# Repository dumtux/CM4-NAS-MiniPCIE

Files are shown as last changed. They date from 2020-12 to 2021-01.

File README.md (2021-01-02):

**Rapberry PI compute module 4 NAS PCB for using JLCPCB.com. (pre-test version)**

# General view of PCB based on processing gbr files on JLCPCB.com

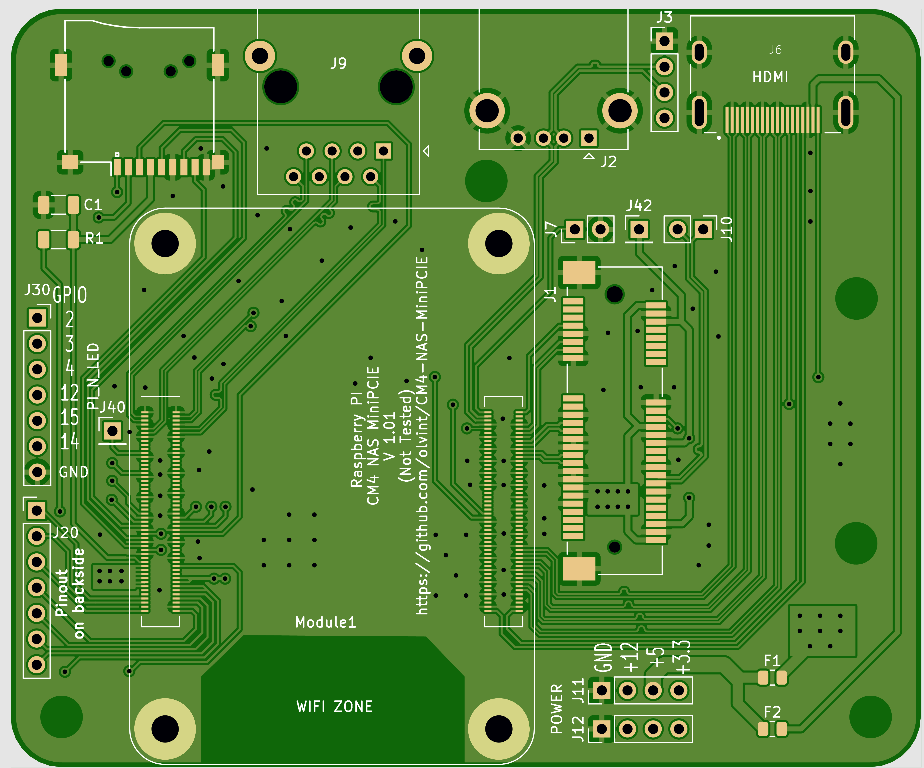
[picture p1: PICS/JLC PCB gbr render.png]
PCB_view


Main purpose of design is to make NAS with more reliable SATA connection comparing to USB-to-SATA converters. SATA controllers can be connected through MiniPCIe slot. There are variety of cards in market, mainly my intend was to use this for 2 SATA (see picture below). This is half size card. Cards for 4 SATA with RAID controller also can be connected. 

**Design is made using nighly version of KiCAD 5.99.0**
**Please study Raspberry PI CM4 datasheet**

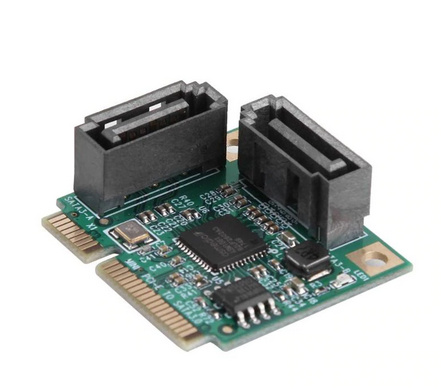
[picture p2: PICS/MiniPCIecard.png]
card


# Differential lines
*PCB was designed by a newcomer. All steps made are listed below. This section is very important and risky. Mistakes can be made.  90 R and 100R impedance differential lines are used.Calculations of differential lines are made using JLCPCB internal [calculator](https://cart.jlcpcb.com/impedanceCalculation)*

Results of calculation - [90R](https://raw.githubusercontent.com/olvint/CM4-NAS-MiniPCIE/main/PICS/JLCPCB%20Impedance%2090R.png) and [100R](https://raw.githubusercontent.com/olvint/CM4-NAS-MiniPCIE/main/PICS/JLCPCB%20Impedance%20100R.png)

Those results put in KiCAD.
KiCAD_Layers

JLC7628 [Stackup](https://cart.jlcpcb.com/impedance) used all settings transfered to [KiCAD stackup](https://raw.githubusercontent.com/olvint/CM4-NAS-MiniPCIE/main/PICS/KiCAD%20Stack.png)

All vias minimal diameter is 0.45 as price will be much higher for VIAs of less size.

# PCB description
## Sockets on PCB
- MiniPCIe slot (designed for hlaf-size cards)
- HDMI in order to use device as media player
- Gigabit LAN
- SD card slot for using CM4’s without eMMC
- USB A 2.0 socket for connecting periphery like Zigbee.
- MicroUSB for installing firmware to CM4 and power supply.
All sockets placed on top edge of PCB for more reliable use and easy design of 3D print case.

## Footprints
All sockets footprints selected to be most common. In standard library of  KiCAD I did not found suitable MicroSD socket. And ofcource footprint of CM4 is also taken from Raspberry PI CM4 IO borad. All external footprints are in folder LIBS.
I wanted to install all sockets on one side of the board and there was not much space. MicroUSB socket I put on other side of the board below MicroSD socket.

## On board connectors.
### Power input. 
There are 2 connectors with 4 pins (GND, +12V, +5V, +3.3V) Connectors can be used for powering board and soldering cable for powering HDDs. 
- +12 V is only used for HDD. Board has 2 interconnected pins, but level +12 V not used on board. MiniPCIe does not have +12V input.
- +5V used for powering CM4 module and giving power to USB and HDMI. Two SMD resettable fuses installed to protect board from short circuit. 
- +3.3 V used for powering PCI-to-SATA module. Nothing else.
- 1.5 V. Special connector made above PCIe slot.  Generaly this level is not required. It is planned to use SATA module based on chip ASM1061 that has [Integrated 3.3V to 1.2V switch regulator](https://www.asmedia.com.tw/eng/e_show_products.php?cate_index=166&item=118). 

Initial CM4 IO Borad has more copmplicated power system with different ICs for protecting not only from short circuit but, under voltage, overload etc.

### GPIO.
Left side of board has GPIO connector and small connector for selecting level of GPIO (GPIO_Vref)
- GPIO 2
- GPIO 3
- GPIO 4
- GPIO 12
- GPIO 15
- GPIO 14

### Service conections and LEDs
There is a connector with following signals
- nRPIBOOT
- PI_POWER_LED
- Global_EN
- nEXTRST
- Analog_P1
- Analog_P0
- RUN_PG
- PI_N_LED

### Other connectors
- USG_OTG connector used to connect USB_OTG_ID pin of CM4 for installing firmware to eMMC. 
- USB hub connecor Connector with 4 pins GND, D+, D-, +5V can be used to connect external USB hub if you need it in your project.
- MiniPCIe USB D+/D-. MiniPCIe slot also has connections for D+ and D- another connector used for it. This is not connected to CM4 D+/D- lines.
- One GND connector just for the case.

### GBR files
GBR files are prepared in [FAB](https://github.com/olvint/CM4-NAS-MiniPCIE/tree/main/FAB) folder. Also archive prepared FAB_JLCPCB.zip for making order. *Please note that you need to turn on option **Impedance** and select JLCPCB7628 stackup*

### KiCAD view
Front
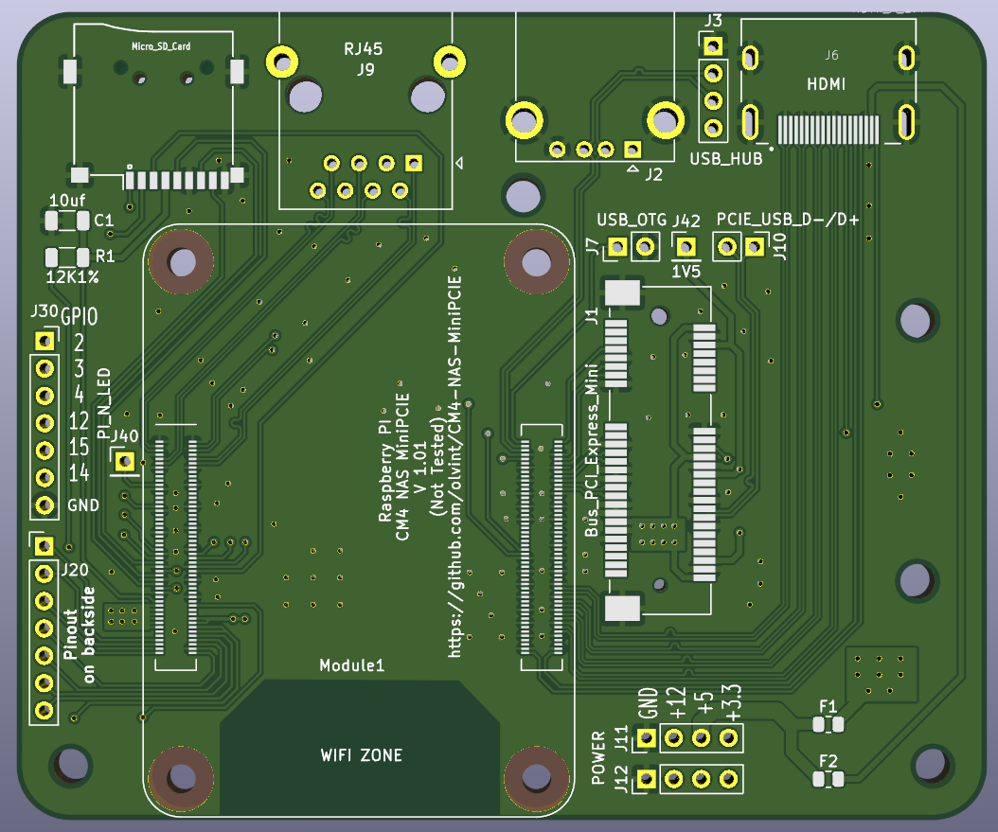
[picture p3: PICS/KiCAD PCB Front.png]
Front


Back
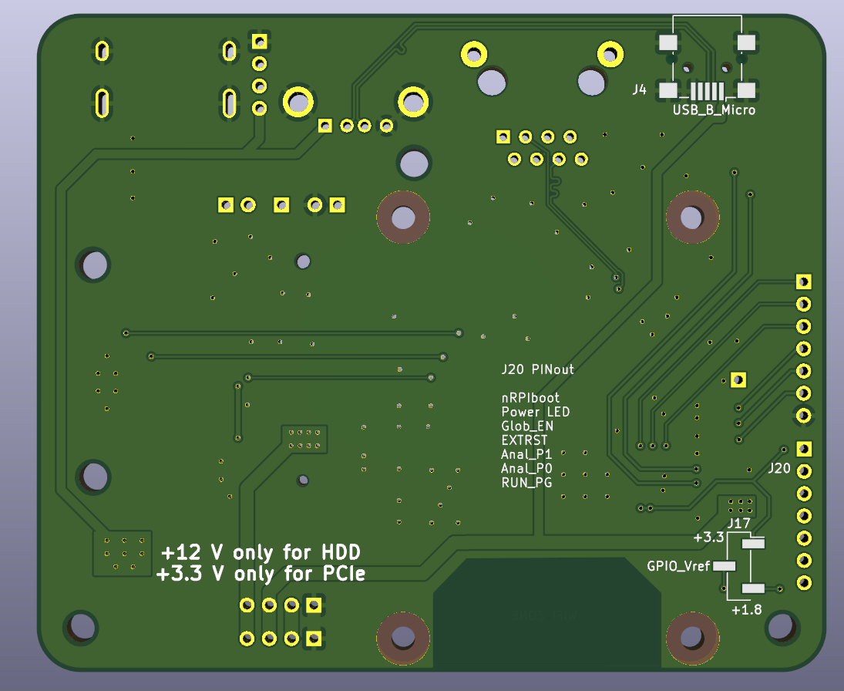
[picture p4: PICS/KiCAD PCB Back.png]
Back


Update 28.12.2020 - Rerouted some tracks. Moved MicroUSB below MicroSD.
Update 02.01.2021 - Rerouted a lot of tracks. Added beauty.

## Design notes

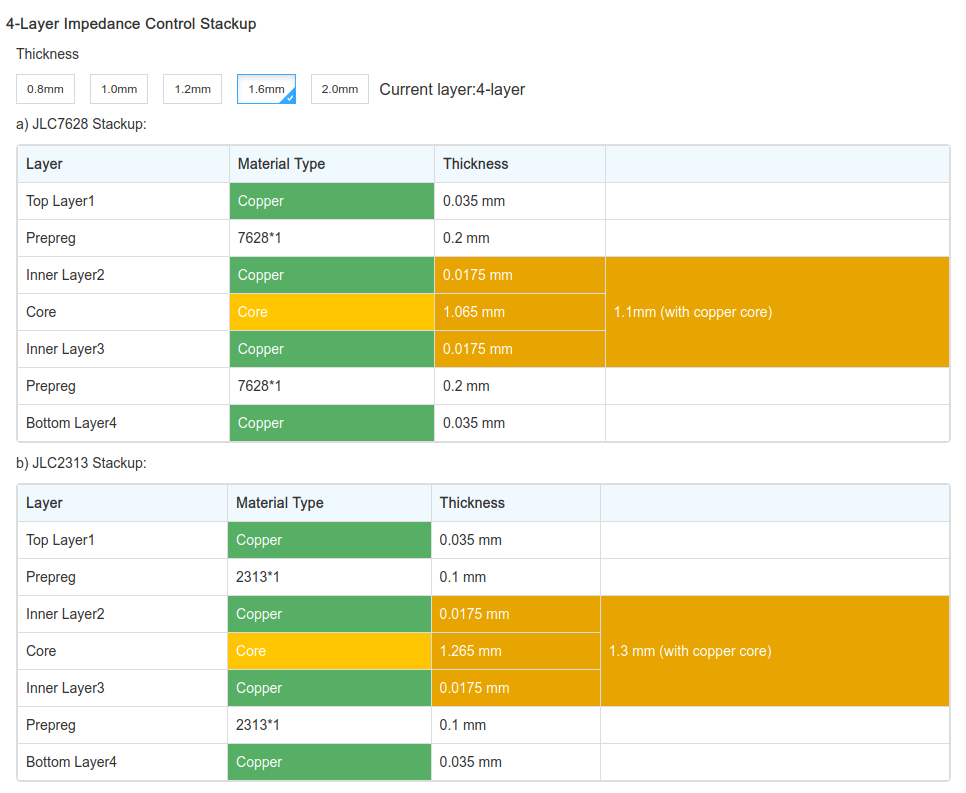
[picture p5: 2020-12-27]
PICS/JLCPCB Stack.png

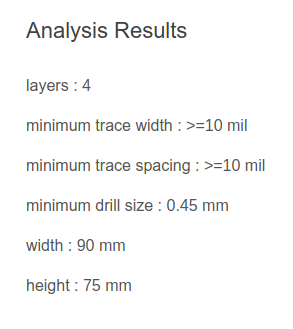
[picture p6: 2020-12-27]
PICS/JLCPCB Analysis.png

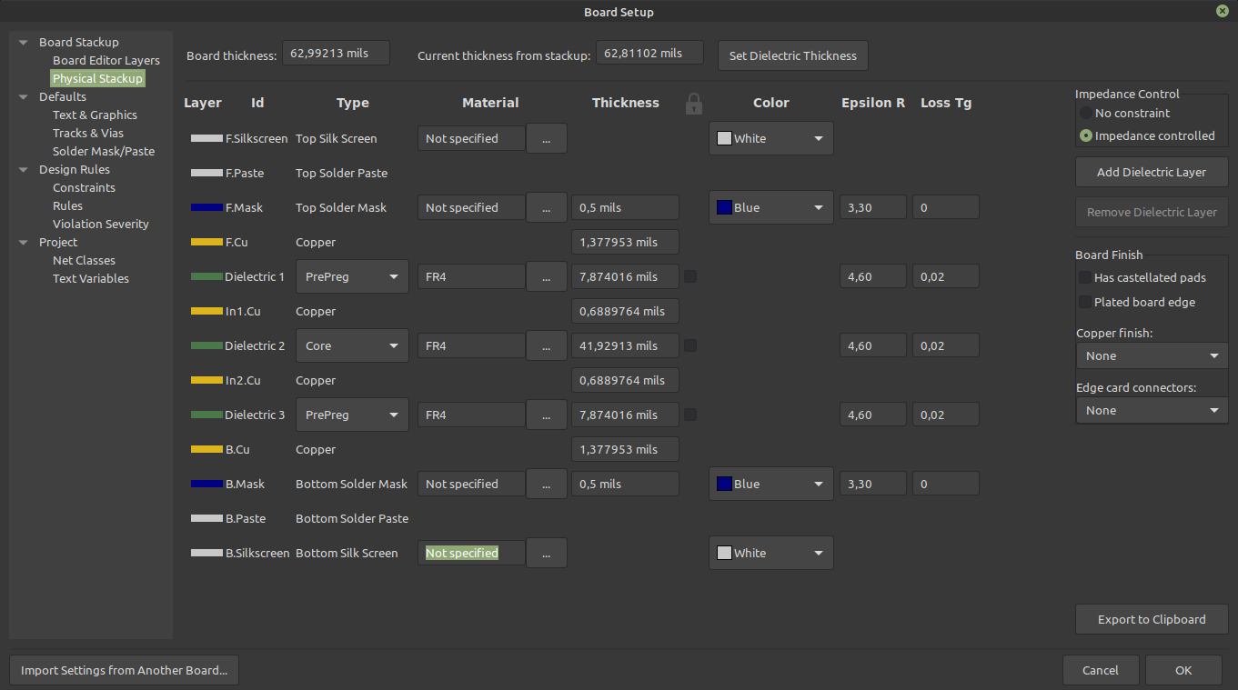
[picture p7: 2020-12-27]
PICS/KiCAD Stack.png

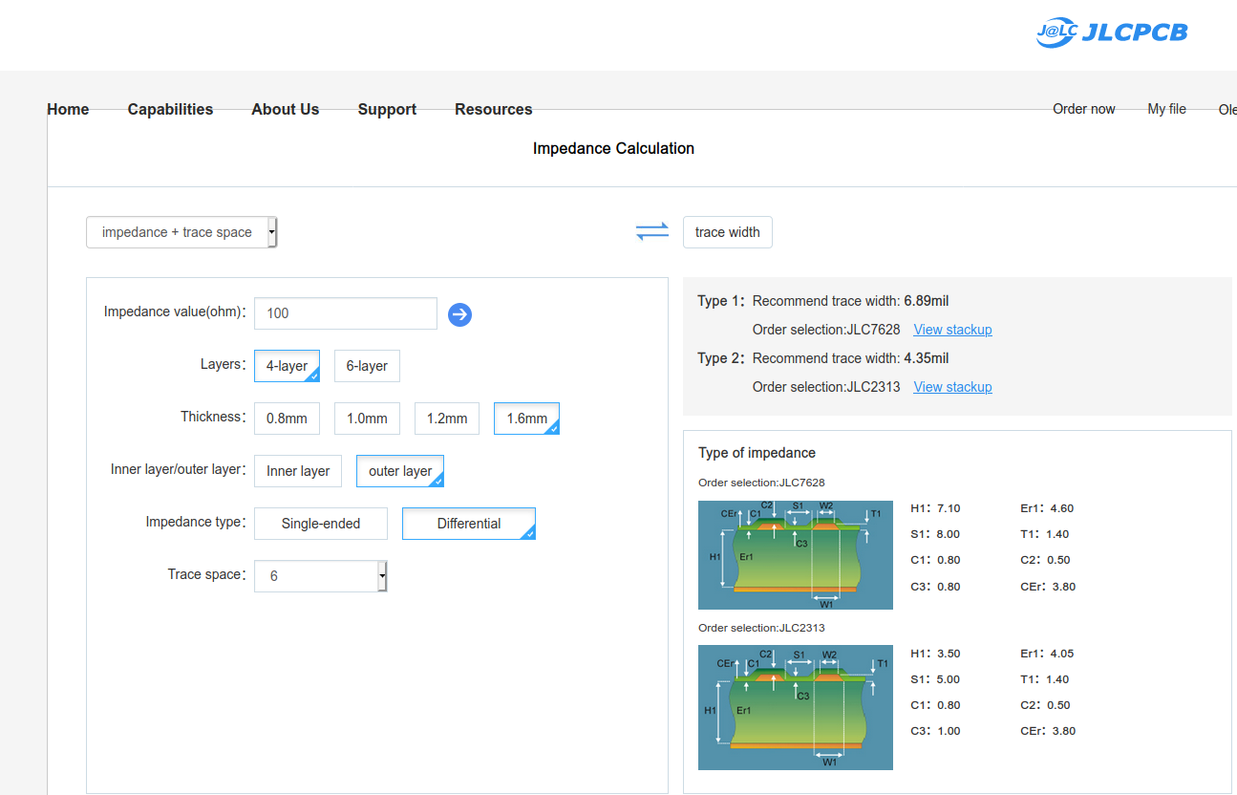
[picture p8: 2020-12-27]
PICS/JLCPCB Impedance 100R.png

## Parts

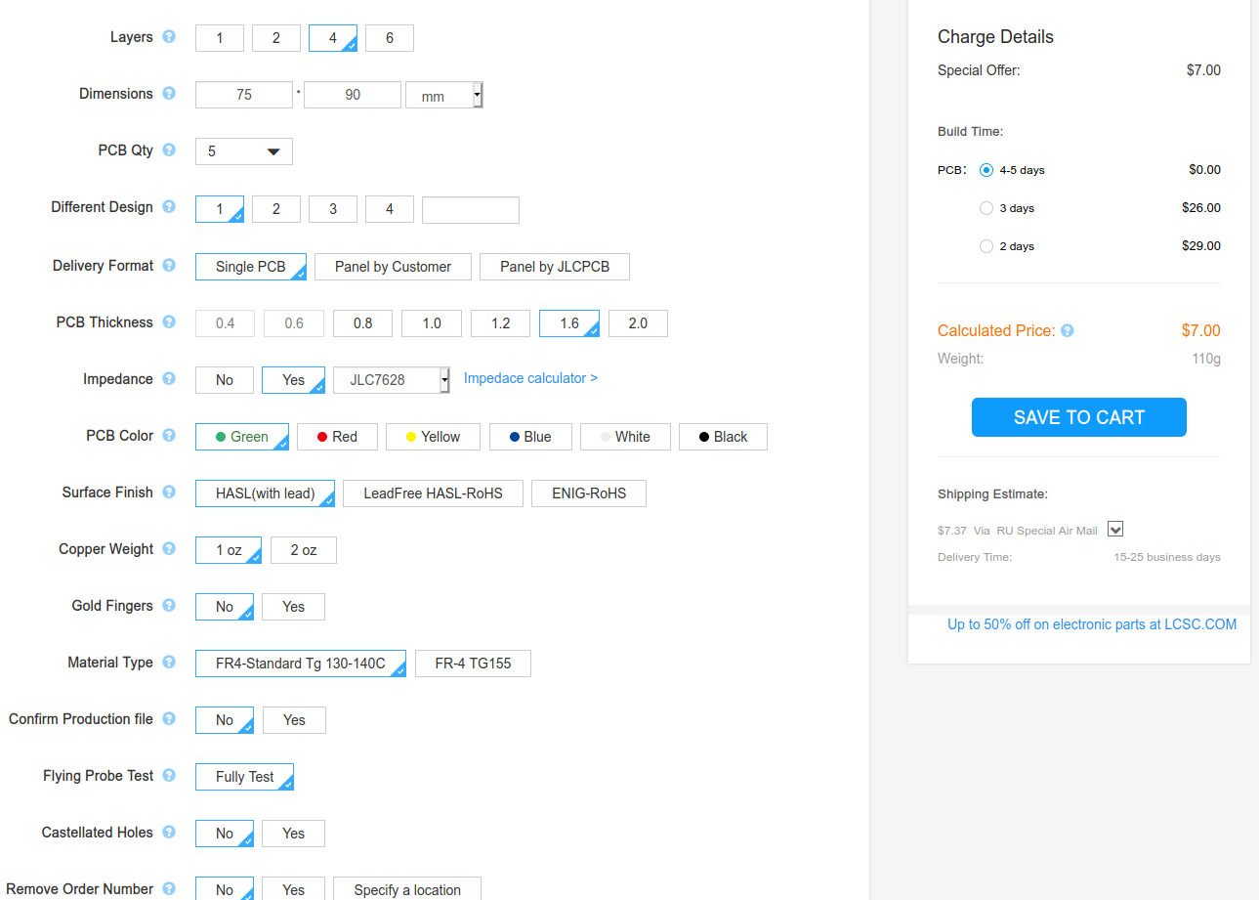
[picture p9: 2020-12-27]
PICS/JLC PCB Order.png

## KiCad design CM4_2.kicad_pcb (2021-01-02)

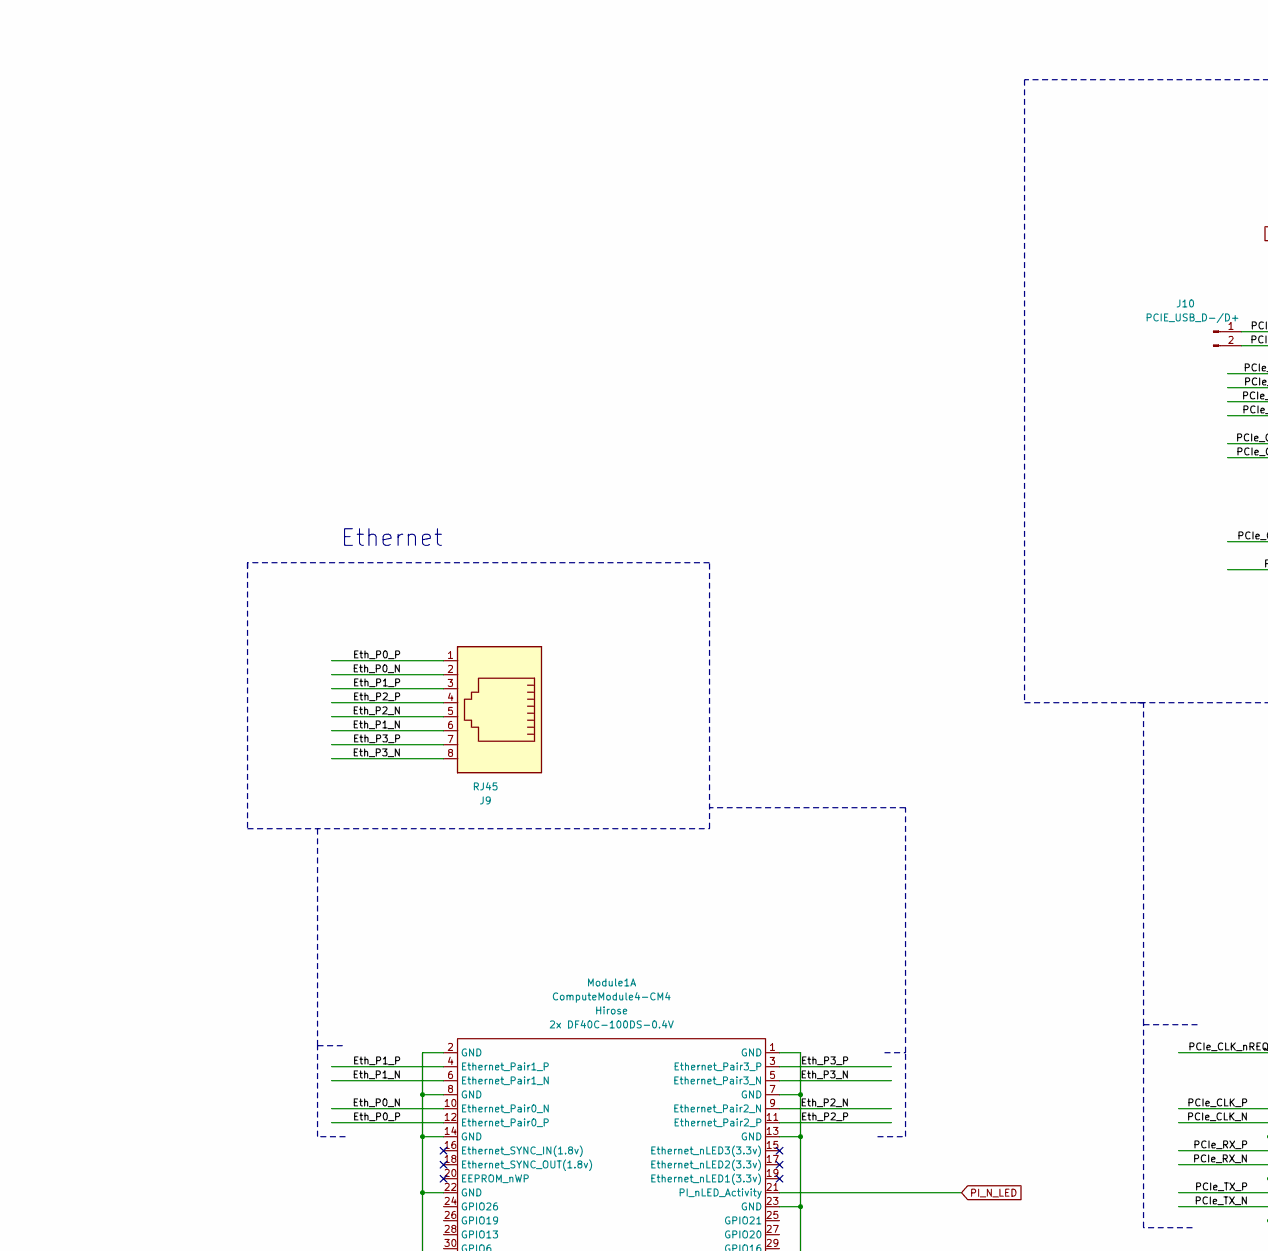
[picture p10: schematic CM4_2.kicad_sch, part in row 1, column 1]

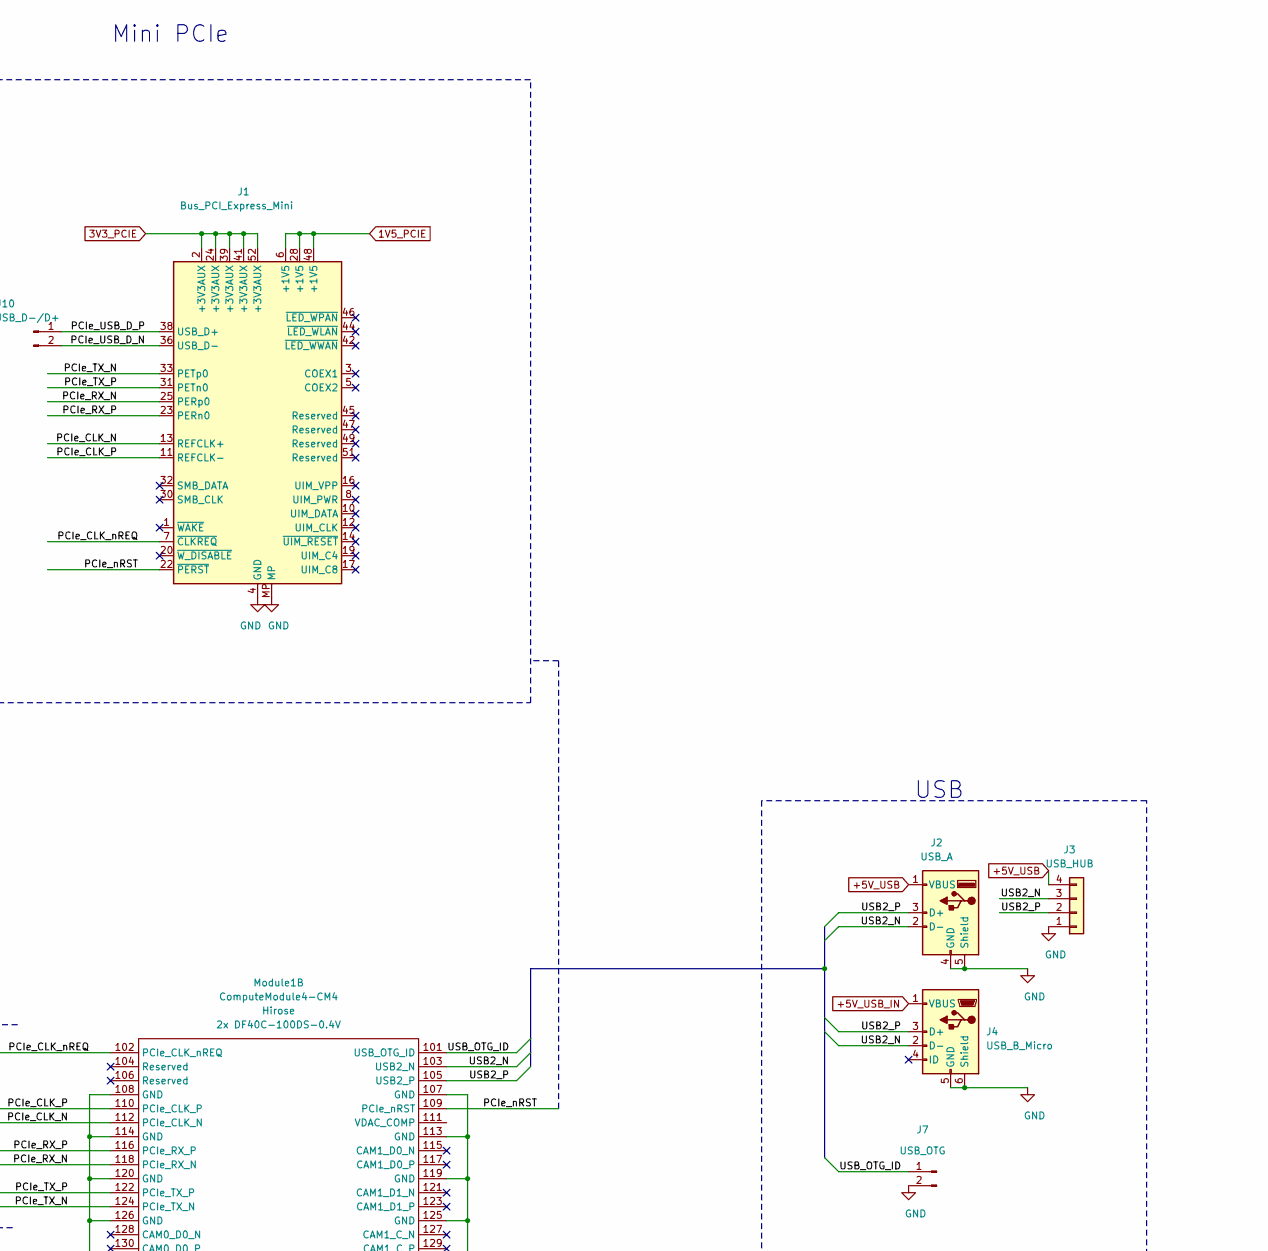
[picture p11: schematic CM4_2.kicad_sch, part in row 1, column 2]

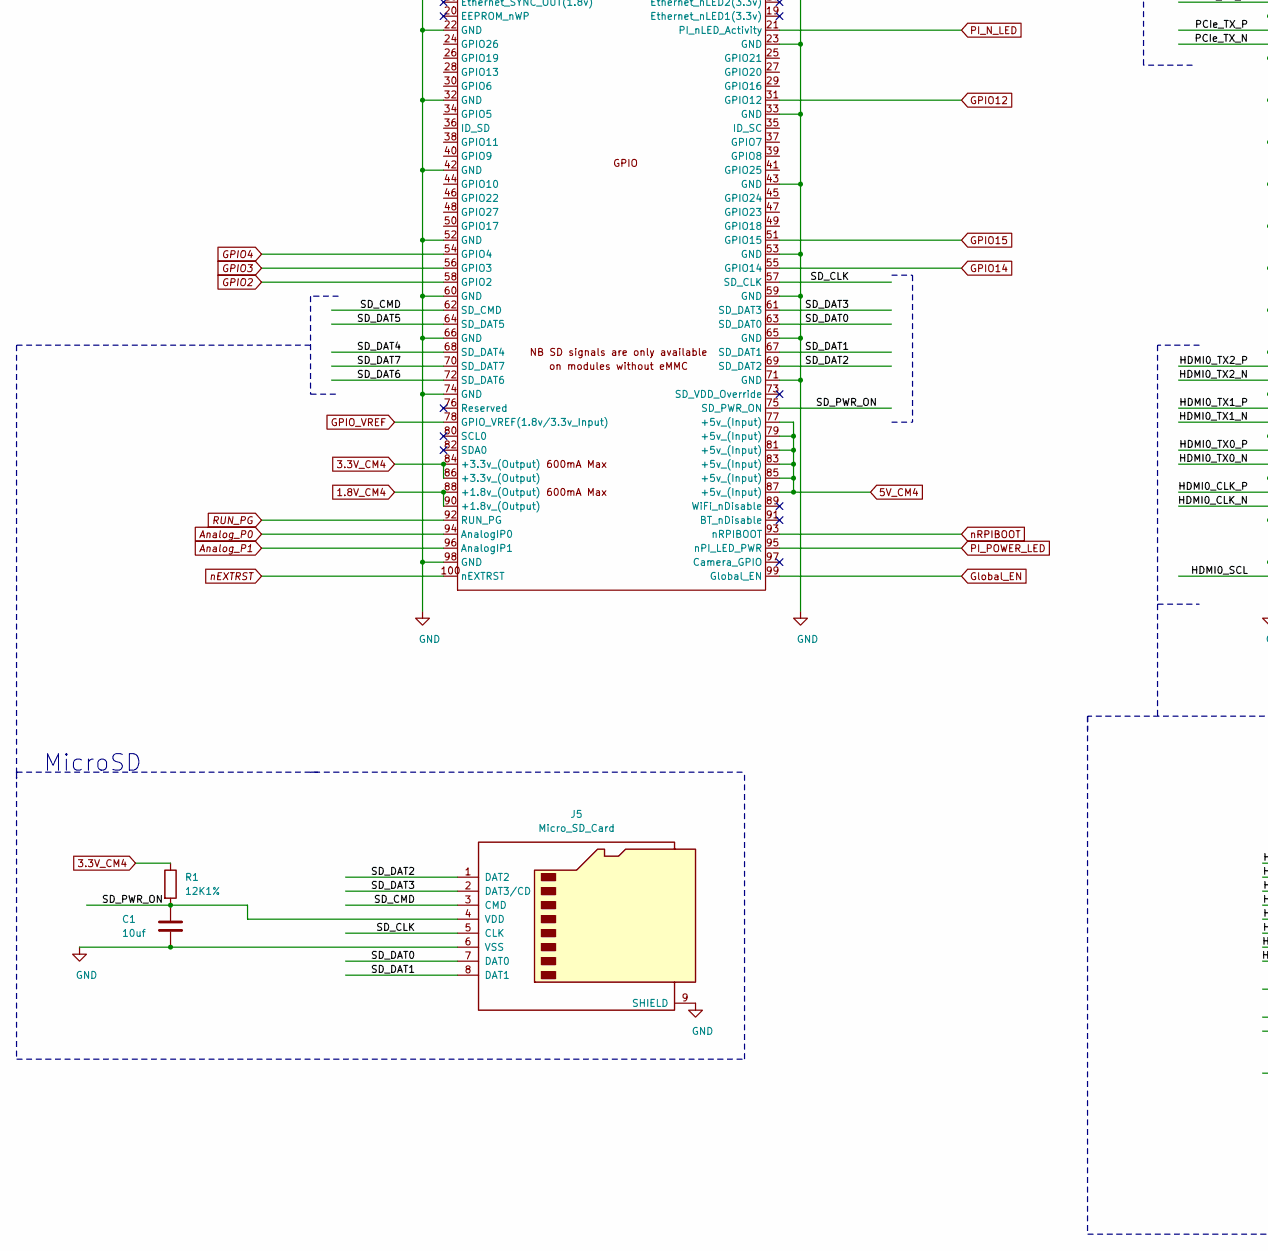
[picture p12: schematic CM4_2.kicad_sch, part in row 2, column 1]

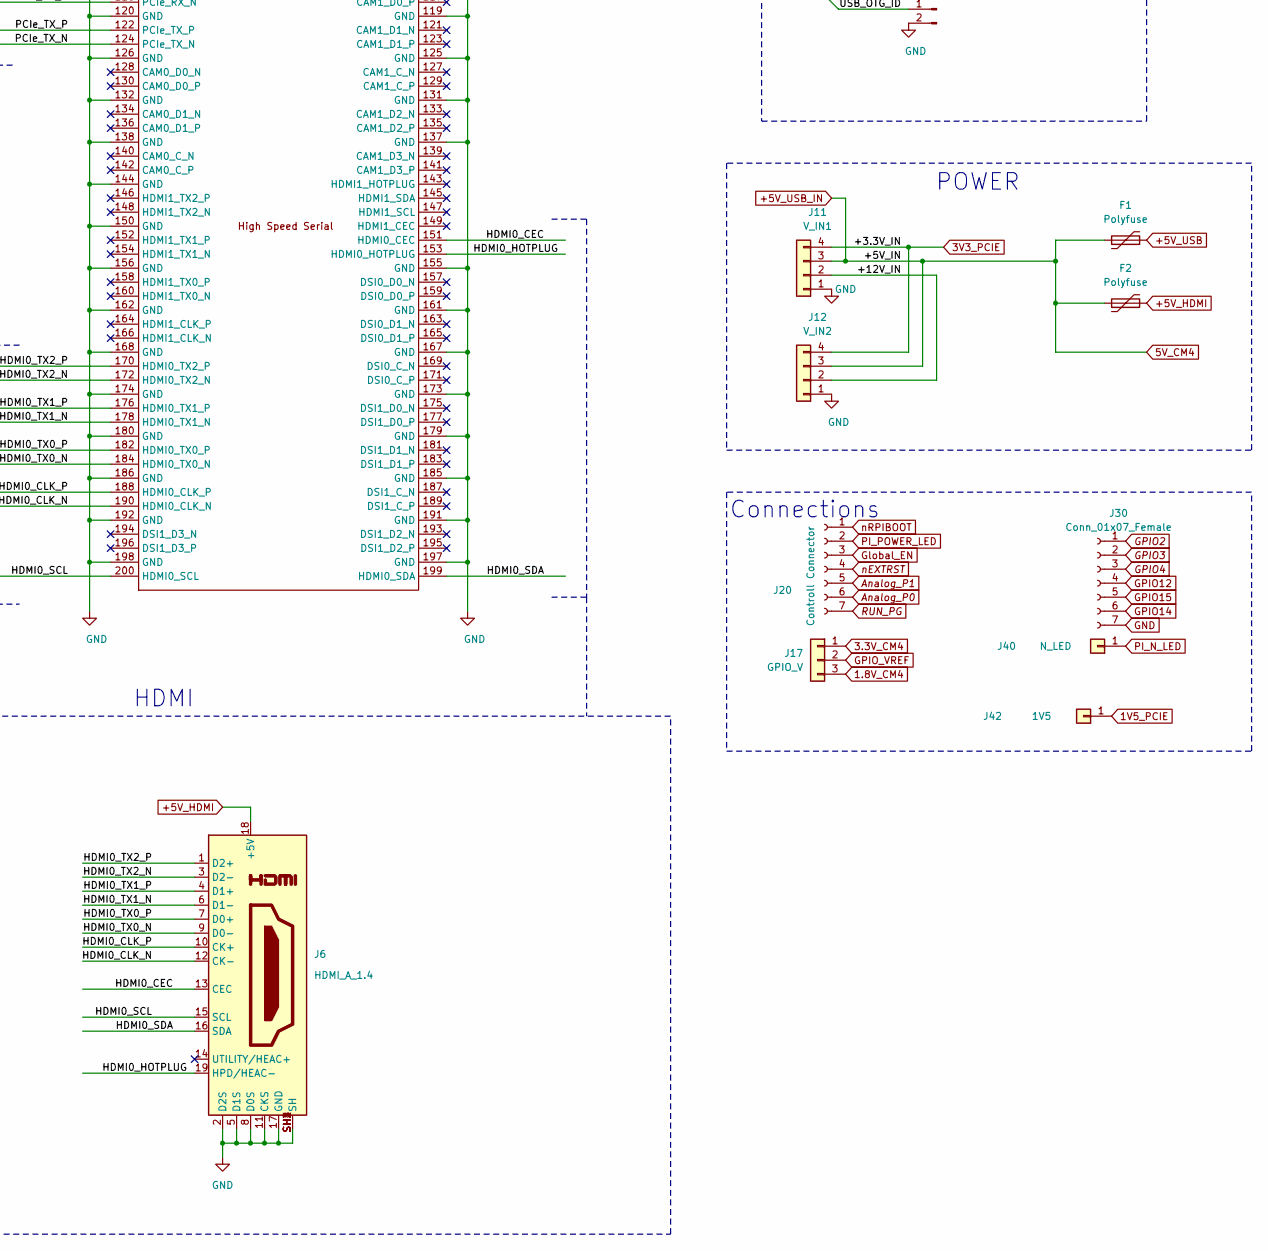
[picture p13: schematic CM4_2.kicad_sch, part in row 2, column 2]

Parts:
C1: 10uf; C_1206_3216Metric
F1, F2: Polyfuse; R_0805_2012Metric
J1: Bus_PCI_Express_Mini; BUS_PCI_Express_Mini_Half
J2: USB_A; USB_A_CONNFLY_DS1095-WNR0
J3: USB_HUB; PinHeader_1x04_P2.54mm_Vertical
J4: USB_B_Micro; USB_Mini-B_Lumberg_2486_01_Horizontal
J5: Micro_SD_Card; Conn_uSDcard
J6: HDMI_A_1.4; EDAC 690-019-298-412
J7: USB_OTG; PinHeader_1x02_P2.54mm_Vertical
J9: RJ45; RJ45_Ninigi_GE
J10: PCIE_USB_D-/D+; PinHeader_1x02_P2.54mm_Vertical
J11: V_IN1; PinHeader_1x04_P2.54mm_Vertical
J12: V_IN2; PinHeader_1x04_P2.54mm_Vertical
J17: GPIO_V; PinHeader_1x03_P2.54mm_Vertical_SMD_Pin1Right
J20: Controll Connector; PinHeader_1x07_P2.54mm_Vertical
J30: Conn_01x07_Female; PinSocket_1x07_P2.54mm_Vertical
J40: N_LED; PinHeader_1x01_P2.54mm_Vertical
J42: 1V5; PinHeader_1x01_P2.54mm_Vertical
Module1: ComputeModule4-CM4; Raspberry-Pi-4-Compute-Module
R1: 12K1%; R_1206_3216Metric

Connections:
1.8V_CM4: J17.3, Module1.88 (+1.8v_(Output)), Module1.90 (+1.8v_(Output))
1V5_PCIE: J1.6 (+1V5), J1.28 (+1V5), J1.48 (+1V5), J42.1
3.3V_CM4: J17.1, Module1.84 (+3.3v_(Output)), Module1.86 (+3.3v_(Output)), R1.1
3V3_PCIE: J1.2 (+3V3AUX), J1.24 (+3V3AUX), J1.39 (+3V3AUX), J1.41 (+3V3AUX), J1.52 (+3V3AUX), J11.4, J12.4
+5V_HDMI: F2.2, J6.18 (+5V)
+5V_USB: F1.2, J2.1 (VBUS), J3.4
+5V_USB_IN: F1.1, F2.1, J4.1 (VBUS), J11.3, J12.3, Module1.77 (+5v_(Input)), Module1.79 (+5v_(Input)), Module1.81 (+5v_(Input)), Module1.83 (+5v_(Input)), Module1.85 (+5v_(Input)), Module1.87 (+5v_(Input))
/+12V_IN: J11.2, J12.2
/Eth_P0_N: J9.2, Module1.10 (Ethernet_Pair0_N)
/Eth_P0_P: J9.1, Module1.12 (Ethernet_Pair0_P)
/Eth_P1_N: J9.6, Module1.6 (Ethernet_Pair1_N)
/Eth_P1_P: J9.3, Module1.4 (Ethernet_Pair1_P)
/Eth_P2_N: J9.5, Module1.9 (Ethernet_Pair2_N)
/Eth_P2_P: J9.4, Module1.11 (Ethernet_Pair2_P)
/Eth_P3_N: J9.8, Module1.5 (Ethernet_Pair3_N)
/Eth_P3_P: J9.7, Module1.3 (Ethernet_Pair3_P)
/HDMI0_CEC: J6.13 (CEC), Module1.151 (HDMI0_CEC)
/HDMI0_CLK_N: J6.12 (CK-), Module1.190 (HDMI0_CLK_N)
/HDMI0_CLK_P: J6.10 (CK+), Module1.188 (HDMI0_CLK_P)
/HDMI0_HOTPLUG: J6.19 (HPD/HEAC-), Module1.153 (HDMI0_HOTPLUG)
/HDMI0_SCL: J6.15 (SCL), Module1.200 (HDMI0_SCL)
/HDMI0_SDA: J6.16 (SDA), Module1.199 (HDMI0_SDA)
/HDMI0_TX0_N: J6.9 (D0-), Module1.184 (HDMI0_TX0_N)
/HDMI0_TX0_P: J6.7 (D0+), Module1.182 (HDMI0_TX0_P)
/HDMI0_TX1_N: J6.6 (D1-), Module1.178 (HDMI0_TX1_N)
/HDMI0_TX1_P: J6.4 (D1+), Module1.176 (HDMI0_TX1_P)
/HDMI0_TX2_N: J6.3 (D2-), Module1.172 (HDMI0_TX2_N)
/HDMI0_TX2_P: J6.1 (D2+), Module1.170 (HDMI0_TX2_P)
/PCIe_CLK_N: J1.13 (REFCLK+), Module1.112 (PCIe_CLK_N)
/PCIe_CLK_P: J1.11 (REFCLK-), Module1.110 (PCIe_CLK_P)
/PCIe_CLK_nREQ: J1.7 (~CLKREQ), Module1.102 (PCIe_CLK_nREQ)
/PCIe_RX_N: J1.25 (PERp0), Module1.118 (PCIe_RX_N)
/PCIe_RX_P: J1.23 (PERn0), Module1.116 (PCIe_RX_P)
/PCIe_TX_N: J1.33 (PETp0), Module1.124 (PCIe_TX_N)
/PCIe_TX_P: J1.31 (PETn0), Module1.122 (PCIe_TX_P)
/PCIe_USB_D_N: J1.36 (USB_D-), J10.2
/PCIe_USB_D_P: J1.38 (USB_D+), J10.1
/PCIe_nRST: J1.22 (~PERST), Module1.109 (PCIe_nRST)
/SD_CLK: J5.5 (CLK), Module1.57 (SD_CLK)
/SD_CMD: J5.3 (CMD), Module1.62 (SD_CMD)
/SD_DAT0: J5.7 (DAT0), Module1.63 (SD_DAT0)
/SD_DAT1: J5.8 (DAT1), Module1.67 (SD_DAT1)
/SD_DAT2: J5.1 (DAT2), Module1.69 (SD_DAT2)
/SD_DAT3: J5.2 (DAT3/CD), Module1.61 (SD_DAT3)
/SD_DAT4: Module1.68 (SD_DAT4)
/SD_DAT5: Module1.64 (SD_DAT5)
/SD_DAT6: Module1.72 (SD_DAT6)
/SD_DAT7: Module1.70 (SD_DAT7)
/SD_PWR_ON: C1.1, J5.4 (VDD), Module1.75 (SD_PWR_ON), R1.2
/USB2_N: J2.2 (D-), J3.3, J4.2 (D-), Module1.103 (USB2_N)
/USB2_P: J2.3 (D+), J3.2, J4.3 (D+), Module1.105 (USB2_P)
/USB_OTG_ID: J7.1, Module1.101 (USB_OTG_ID)
Analog_P0: J20.6, Module1.94 (AnalogIP0)
Analog_P1: J20.5, Module1.96 (AnalogIP1)
GND: C1.2, J1.4 (GND), J1.9 (GND), J1.15 (GND), J1.18 (GND), J1.21 (GND), J1.26 (GND), J1.27 (GND), J1.29 (GND), J1.34 (GND), J1.35 (GND), J1.37 (GND), J1.40 (GND), J1.43 (GND), J1.50 (GND), J1.MP, J2.4 (GND), J2.5 (Shield), J3.1, J4.5 (GND), J4.6 (Shield), J5.6 (VSS), J5.9 (SHIELD), J6.2 (D2S), J6.5 (D1S), J6.8 (D0S), J6.11 (CKS), J6.17 (GND), J6.SH1 (SH), J6.SH2 (SH), J6.SH3 (SH), J6.SH4 (SH), J7.2, J11.1, J12.1, J30.7, Module1.1 (GND), Module1.2 (GND), Module1.7 (GND), Module1.8 (GND), Module1.13 (GND), Module1.14 (GND), Module1.22 (GND), Module1.23 (GND), Module1.32 (GND), Module1.33 (GND), Module1.42 (GND), Module1.43 (GND), Module1.52 (GND), Module1.53 (GND), Module1.59 (GND), Module1.60 (GND), Module1.65 (GND), Module1.66 (GND), Module1.71 (GND), Module1.74 (GND), Module1.98 (GND), Module1.107 (GND), Module1.108 (GND), Module1.113 (GND), Module1.114 (GND), Module1.119 (GND), Module1.120 (GND), Module1.125 (GND), Module1.126 (GND), Module1.131 (GND), Module1.132 (GND), Module1.137 (GND), Module1.138 (GND), Module1.144 (GND), Module1.150 (GND), Module1.155 (GND), Module1.156 (GND), Module1.161 (GND), Module1.162 (GND), Module1.167 (GND), Module1.168 (GND), Module1.173 (GND), Module1.174 (GND), Module1.179 (GND), Module1.180 (GND), Module1.185 (GND), Module1.186 (GND), Module1.191 (GND), Module1.192 (GND), Module1.197 (GND), Module1.198 (GND)
GPIO2: J30.1, Module1.58 (GPIO2)
GPIO3: J30.2, Module1.56 (GPIO3)
GPIO4: J30.3, Module1.54 (GPIO4)
GPIO12: J30.4, Module1.31 (GPIO12)
GPIO14: J30.6, Module1.55 (GPIO14)
GPIO15: J30.5, Module1.51 (GPIO15)
GPIO_VREF: J17.2, Module1.78 (GPIO_VREF(1.8v/3.3v_Input))
Global_EN: J20.3, Module1.99 (Global_EN)
PI_N_LED: J40.1, Module1.21 (PI_nLED_Activity)
PI_POWER_LED: J20.2, Module1.95 (nPI_LED_PWR)
RUN_PG: J20.7, Module1.92 (RUN_PG)
nEXTRST: J20.4, Module1.100 (nEXTRST)
nRPIBOOT: J20.1, Module1.93 (nRPIBOOT)
no_connect_92: J1.1 (~WAKE)
no_connect_93: J1.10 (UIM_DATA)
no_connect_94: J1.12 (UIM_CLK)
no_connect_95: J1.14 (~UIM_RESET)
no_connect_96: J1.16 (UIM_VPP)
no_connect_97: J1.17 (UIM_C8)
no_connect_98: J1.19 (UIM_C4)
no_connect_99: J1.20 (~W_DISABLE)
no_connect_100: J1.3 (COEX1)
no_connect_101: J1.30 (SMB_CLK)
no_connect_102: J1.32 (SMB_DATA)
no_connect_103: J1.42 (~LED_WWAN)
no_connect_104: J1.44 (~LED_WLAN)
no_connect_105: J1.45 (Reserved)
no_connect_106: J1.46 (~LED_WPAN)
no_connect_107: J1.47 (Reserved)
no_connect_108: J1.49 (Reserved)
no_connect_109: J1.5 (COEX2)
no_connect_110: J1.51 (Reserved)
no_connect_111: J1.8 (UIM_PWR)
no_connect_112: J4.4 (ID)
no_connect_113: J6.14 (UTILITY/HEAC+)
no_connect_114: Module1.104 (Reserved)
no_connect_115: Module1.106 (Reserved)
no_connect_116: Module1.115 (CAM1_D0_N)
no_connect_117: Module1.117 (CAM1_D0_P)
no_connect_118: Module1.121 (CAM1_D1_N)
no_connect_119: Module1.123 (CAM1_D1_P)
no_connect_120: Module1.127 (CAM1_C_N)
no_connect_121: Module1.128 (CAM0_D0_N)
no_connect_122: Module1.129 (CAM1_C_P)
no_connect_123: Module1.130 (CAM0_D0_P)
no_connect_124: Module1.133 (CAM1_D2_N)
no_connect_125: Module1.134 (CAM0_D1_N)
no_connect_126: Module1.135 (CAM1_D2_P)
no_connect_127: Module1.136 (CAM0_D1_P)
no_connect_128: Module1.139 (CAM1_D3_N)
no_connect_129: Module1.140 (CAM0_C_N)
no_connect_130: Module1.141 (CAM1_D3_P)
no_connect_131: Module1.142 (CAM0_C_P)
no_connect_132: Module1.143 (HDMI1_HOTPLUG)
no_connect_133: Module1.145 (HDMI1_SDA)
no_connect_134: Module1.146 (HDMI1_TX2_P)
no_connect_135: Module1.147 (HDMI1_SCL)
no_connect_136: Module1.148 (HDMI1_TX2_N)
no_connect_137: Module1.149 (HDMI1_CEC)
no_connect_138: Module1.15 (Ethernet_nLED3(3.3v))
no_connect_139: Module1.152 (HDMI1_TX1_P)
no_connect_140: Module1.154 (HDMI1_TX1_N)
no_connect_141: Module1.157 (DSI0_D0_N)
no_connect_142: Module1.158 (HDMI1_TX0_P)
no_connect_143: Module1.159 (DSI0_D0_P)
no_connect_144: Module1.16 (Ethernet_SYNC_IN(1.8v))
no_connect_145: Module1.160 (HDMI1_TX0_N)
no_connect_146: Module1.163 (DSI0_D1_N)
no_connect_147: Module1.164 (HDMI1_CLK_P)
no_connect_148: Module1.165 (DSI0_D1_P)
no_connect_149: Module1.166 (HDMI1_CLK_N)
no_connect_150: Module1.169 (DSI0_C_N)
no_connect_151: Module1.17 (Ethernet_nLED2(3.3v))
no_connect_152: Module1.171 (DSI0_C_P)
no_connect_153: Module1.175 (DSI1_D0_N)
no_connect_154: Module1.177 (DSI1_D0_P)
no_connect_155: Module1.18 (Ethernet_SYNC_OUT(1.8v))
no_connect_156: Module1.181 (DSI1_D1_N)
no_connect_157: Module1.183 (DSI1_D1_P)
no_connect_158: Module1.187 (DSI1_C_N)
no_connect_159: Module1.189 (DSI1_C_P)
no_connect_160: Module1.19 (Ethernet_nLED1(3.3v))
no_connect_161: Module1.193 (DSI1_D2_N)
no_connect_162: Module1.194 (DSI1_D3_N)
no_connect_163: Module1.195 (DSI1_D2_P)
no_connect_164: Module1.196 (DSI1_D3_P)
no_connect_165: Module1.20 (EEPROM_nWP)
no_connect_166: Module1.73 (SD_VDD_Override)
no_connect_167: Module1.76 (Reserved)
no_connect_168: Module1.80 (SCL0)
no_connect_169: Module1.82 (SDA0)
no_connect_170: Module1.89 (WiFi_nDisable)
no_connect_171: Module1.91 (BT_nDisable)
no_connect_172: Module1.97 (Camera_GPIO)

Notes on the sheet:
MicroSD
Ethernet
HDMI
Mini PCIe
Connections
USB
POWER

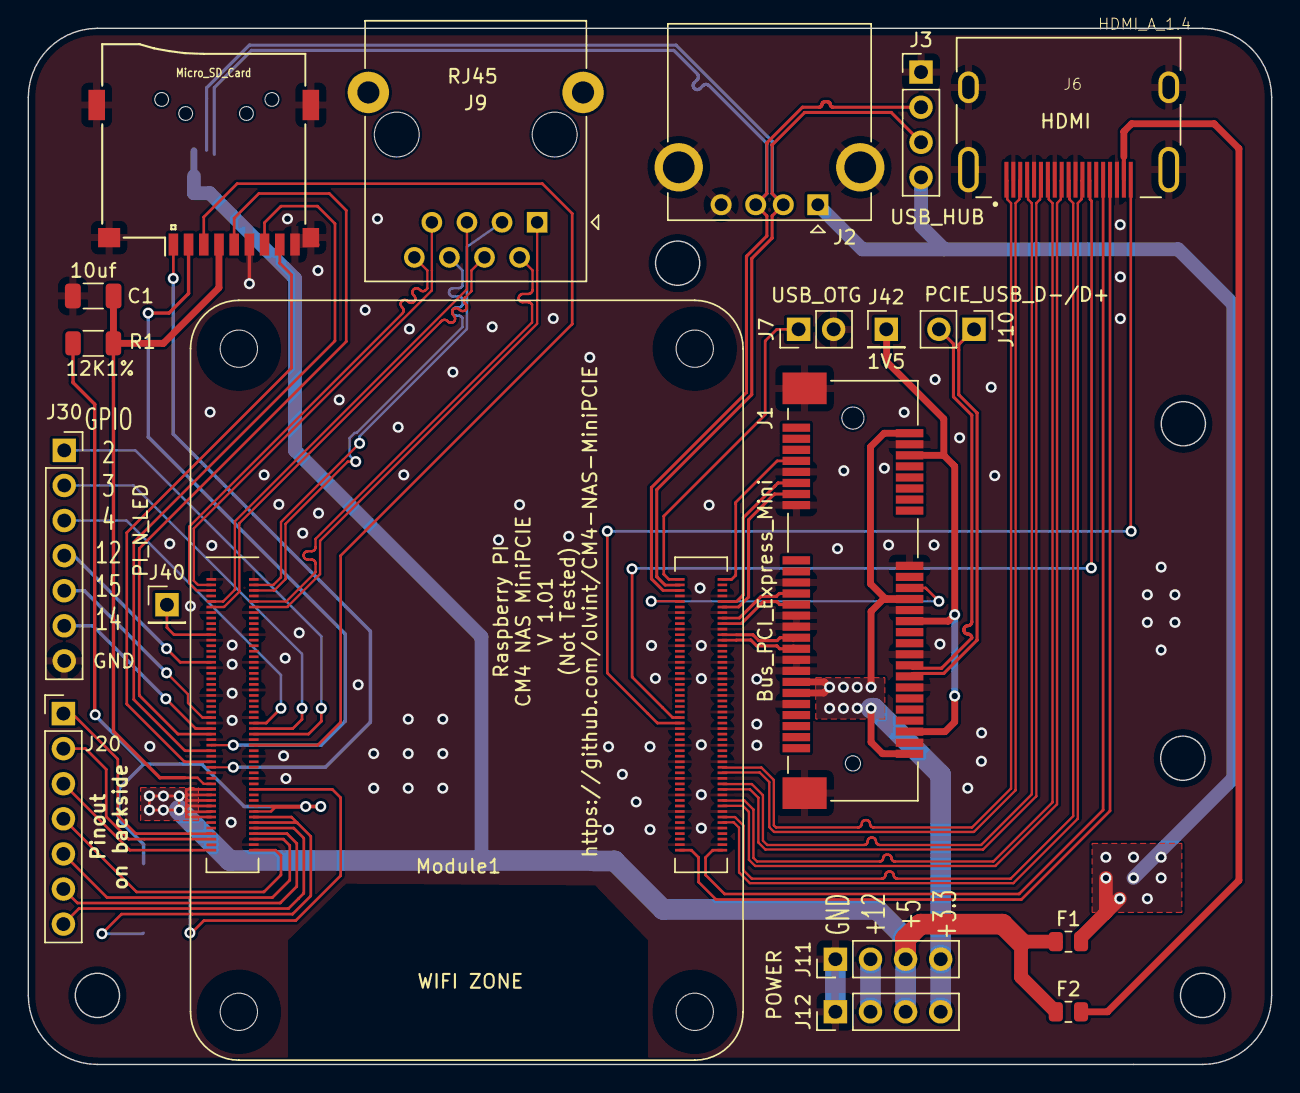
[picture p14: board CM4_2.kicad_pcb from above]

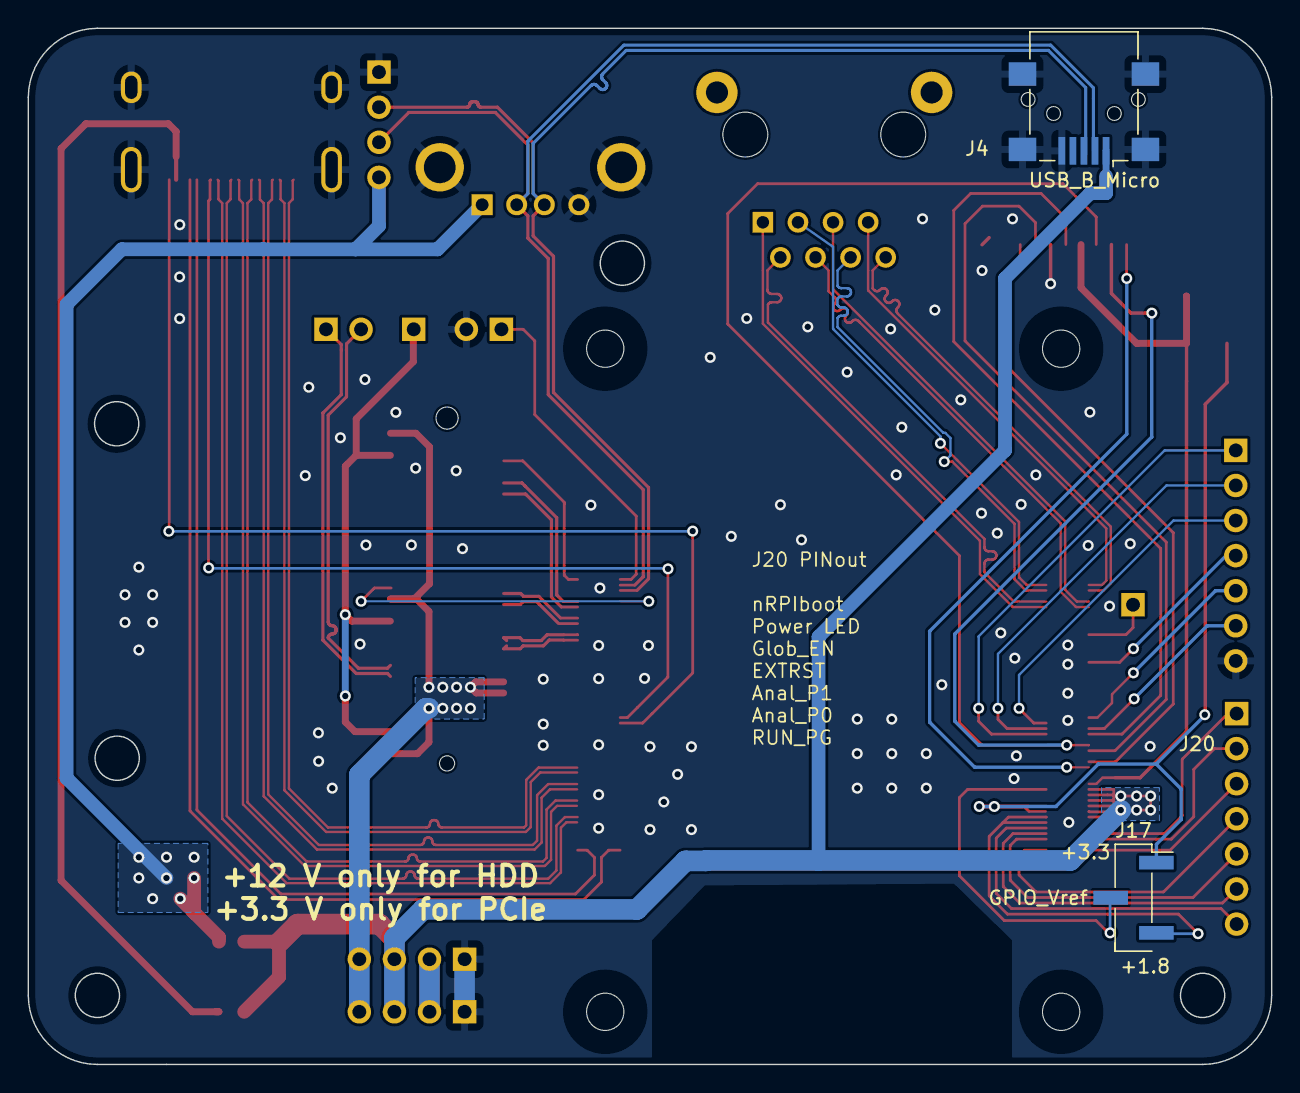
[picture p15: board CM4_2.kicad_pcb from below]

Board: 4 copper layers, 90.0 x 75.0 mm, 21 parts (2 on the bottom side), 64 nets.

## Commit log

2020-12-28 Some tracks rerouted, MicroUSB moved
    [CM4_2-B_Cu.gbr, CM4_2-B_Mask.gbr, CM4_2-B_Paste.gbr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]
2020-12-28 Minor move
    [CM4_2-B_Cu.gbr, CM4_2-B_Mask.gbr, CM4_2-B_Paste.gbr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]
2020-12-28 R2 to R1, C2 to C1
    [CM4_2.kicad_pcb]
2021-01-02 Drill Holes
    [CM4_2-B_Cu.gbr, CM4_2-B_Mask.gbr, CM4_2-B_Paste.gbr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]
